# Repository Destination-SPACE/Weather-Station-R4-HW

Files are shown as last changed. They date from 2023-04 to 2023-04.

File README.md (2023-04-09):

# Destination Weather Station R4 - Hardware
Hardware repository for the Destination Weather Station R4 remote sensing platform

## Features
- Seeeduino XIAO SAMD21 M0 microcontroller
- BME280 environmental sensor
- 128x64 OLED display
- microSD card connector
- STEMMA-QT connector
- Sensor Hat mezzanine connectors (reversable)

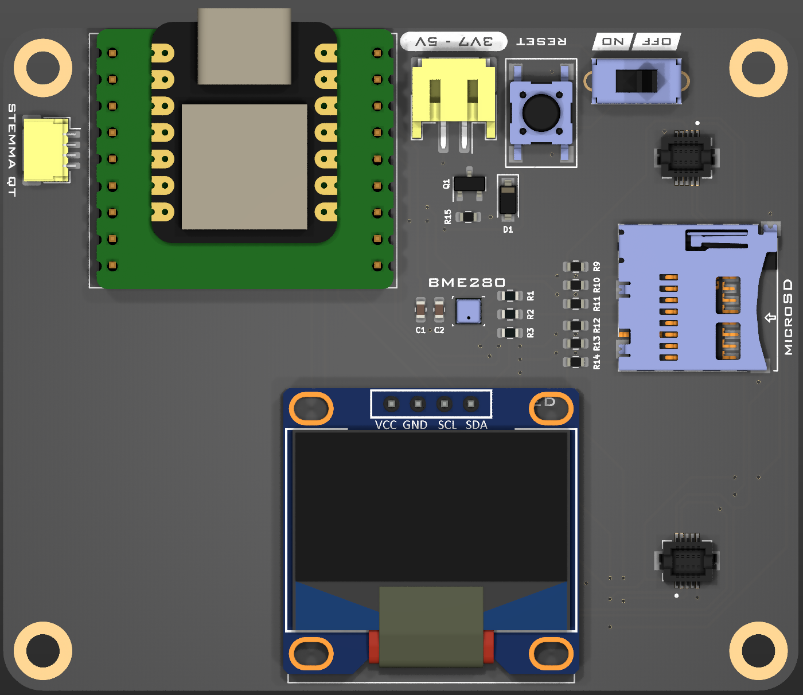
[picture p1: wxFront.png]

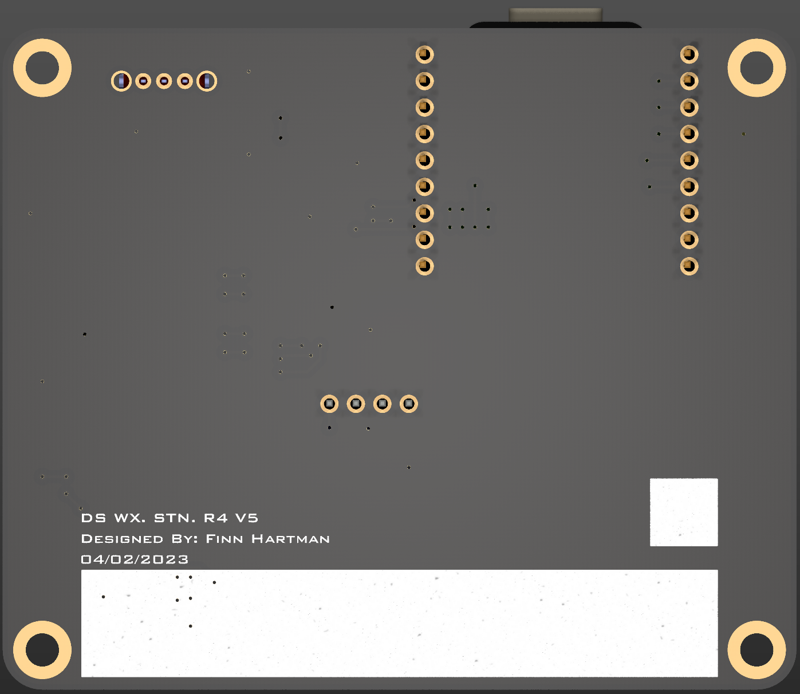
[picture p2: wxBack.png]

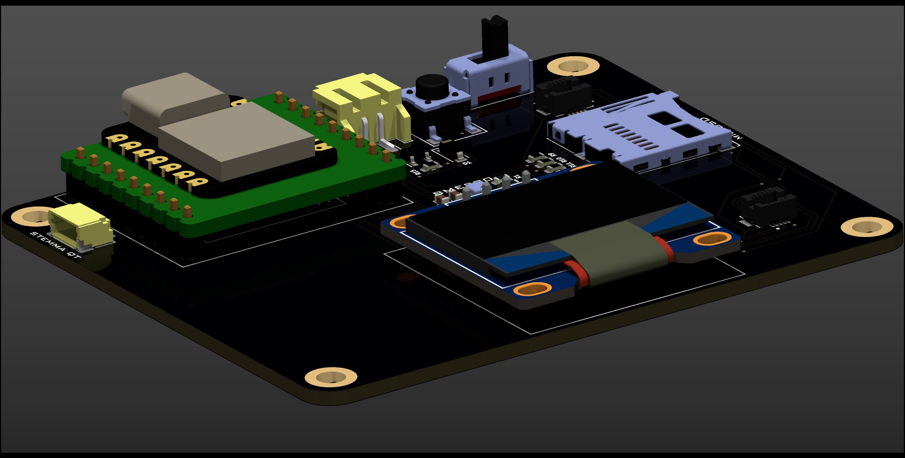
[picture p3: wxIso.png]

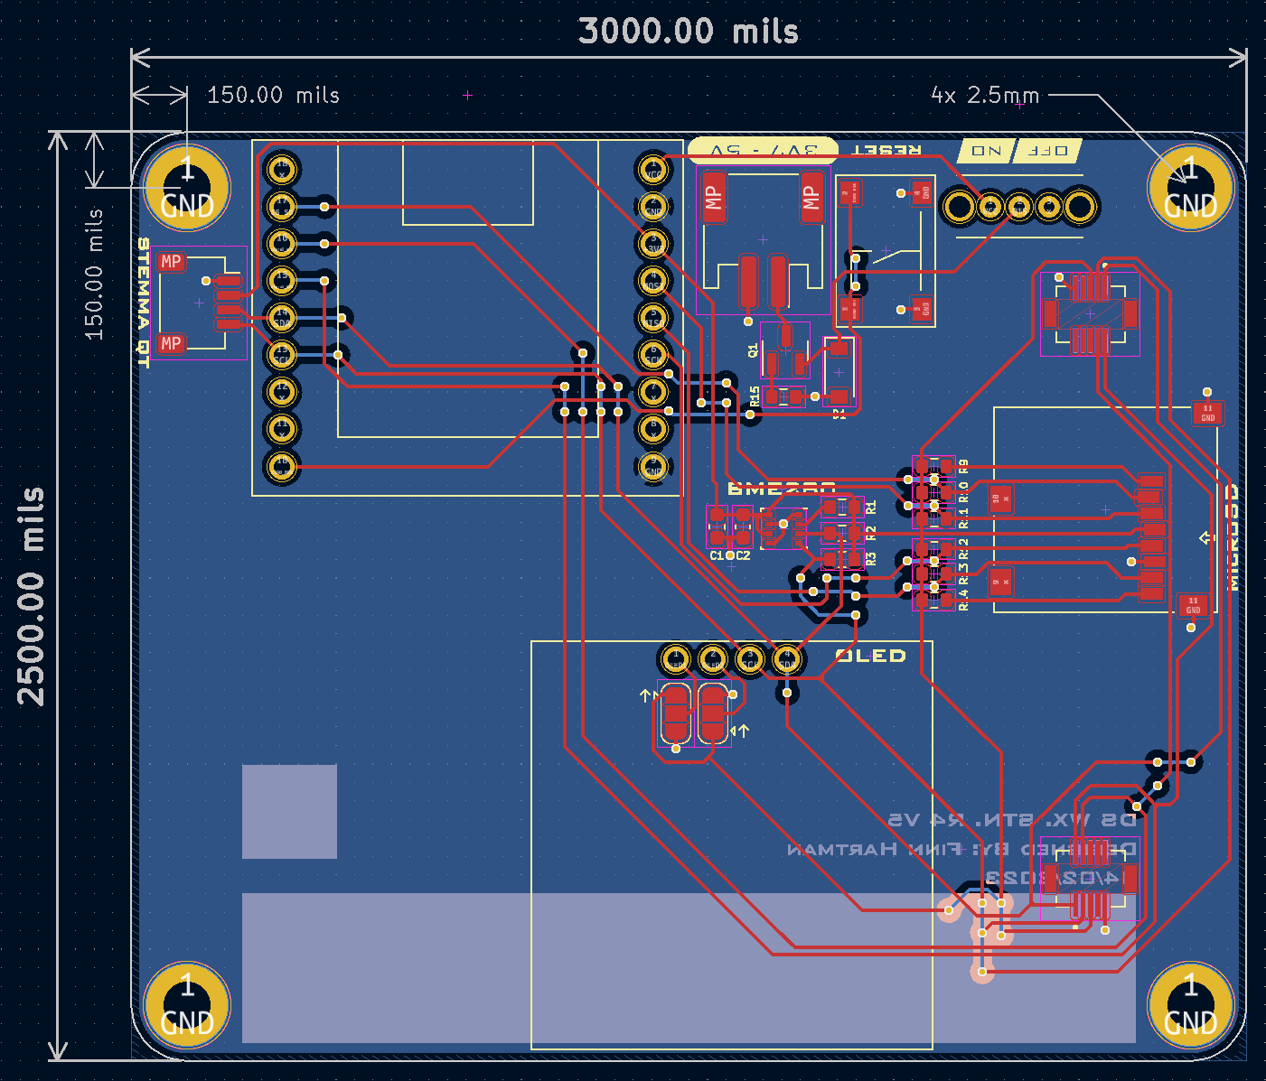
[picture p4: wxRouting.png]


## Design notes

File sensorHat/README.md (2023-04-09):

# Destination Weather Station Sensor Hat - Hardware
Hardware for the Destination Weather Station Sensor Hat environmental sensor expansion board

## Features
- SCD40 CO<sub>2</sub> sensor
- ENS160 VOC & eCO<sub>2</sub> sensor
- GUVA-S12SD UVA (350nm) sensor
- GUVB-S11SD UVB (300nm) sensor
- BH1750 ambient light sensor
- Weather Station mezzanine connectors (reversable)

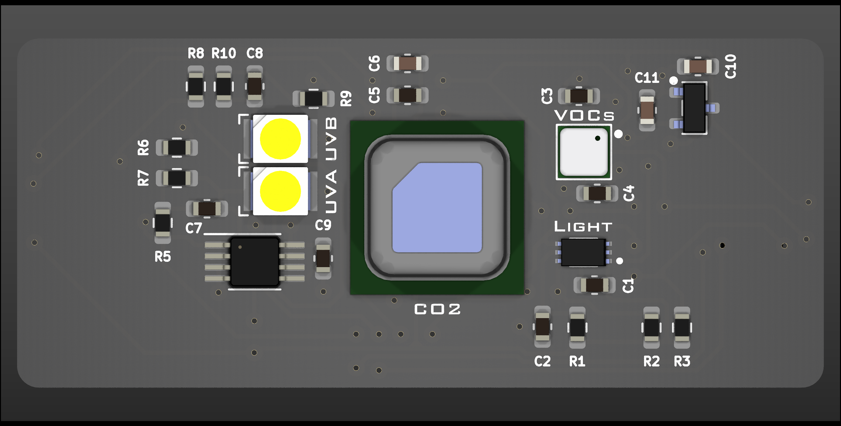
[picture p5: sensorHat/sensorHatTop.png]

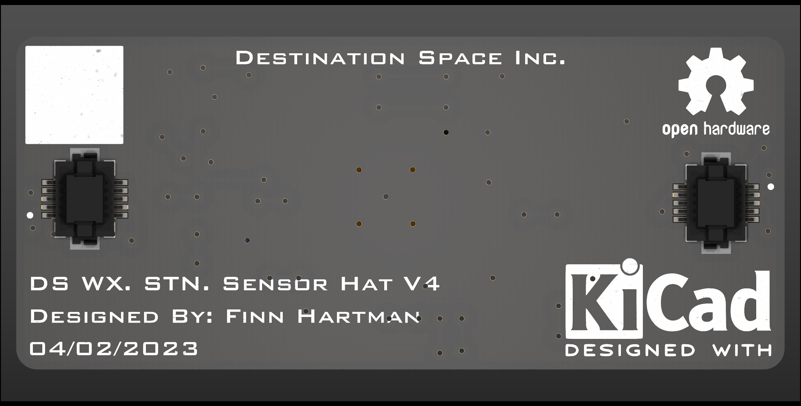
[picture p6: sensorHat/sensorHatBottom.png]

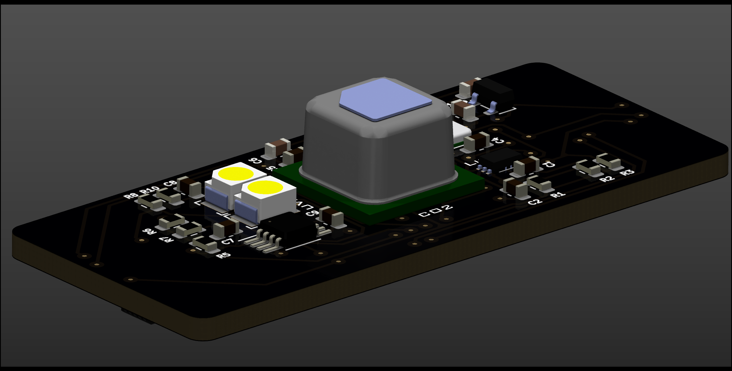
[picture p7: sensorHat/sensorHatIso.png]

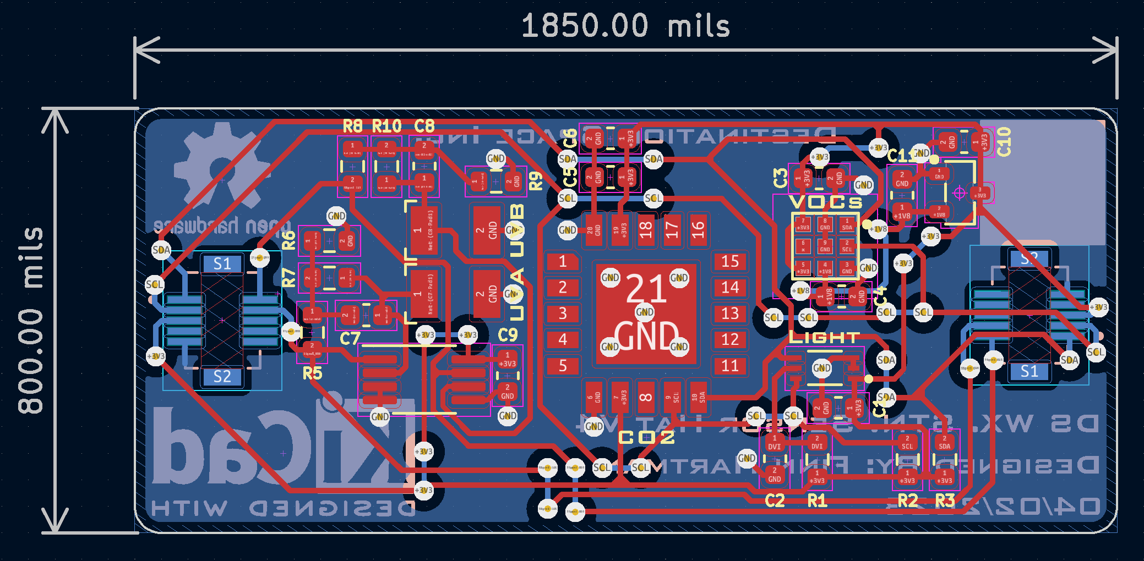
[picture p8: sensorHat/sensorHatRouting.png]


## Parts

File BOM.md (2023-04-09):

| Item | Qty | Reference(s) | Value | Manufacturer | mpn |
| ---- | --- | --- | --- | --- | --- |
| 1 | 2 | C1, C2 | 0.1uF | TDK Corporation | CGA3E2X7R1E104K080AA |
| 2 | 1 | D1 | MMSZ4702T1G | Onsemi | MMSZ4702T1G |
| 4 | 2 | J1, J2 | DF12NB(3.0)-10DP-0.5V(51) | Hirose Electric Co Ltd | DF12NB(3.0)-10DP-0.5V(51) |
| 5 | 1 | J3 | S2B-PH-SM4-TB(LF)(SN) | JST Sales America Inc. | S2B-PH-SM4-TB(LF)(SN) |
| 6 | 1 | J4 | MEM2051-00-195-00-A | GCT | MEM2051-00-195-00-A |
| 7 | 1 | J5 | SM04B-SRSS-TB(LF)(SN) | JST Sales America Inc. | SM04B-SRSS-TB(LF)(SN) |
| 9 | 1 | Q1 | DMP3056L | Diodes Incorporated | DMP3056L-7 |
| 10 | 9 | R1, R2, R3, R9, R10, R11, R12, R13, R14 | 10K | Vishay Dale | CRCW060310K0JNEB |
| 11 | 1 | R15 | 100R | Vishay Dale | CRCW0603100RFKEA |
| 12 | 1 | SW1 | OS102011MS2QS1 | C&K | OS102011MS2QS1 |
| 13 | 1 | SW2 | PTS645SH43SMTR92LFS | C&K | PTS645SH43SMTR92LFS |
| 14 | 1 | U1 | BME280 | Bosch Sensortec | BME280 |
| 15 | 1 | U2 | OLED module | Frienda | B08VNNCLHD |
| 16 | 1 | U3 | Xiao Carrier | Seeed Technology Co., Ltd | 102010328 |

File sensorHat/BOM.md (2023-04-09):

| Item | Qty | Reference(s) | Value | Manufacturer | mpn |
| ---- | --- | --- | --- | --- | --- |
| 1 | 7 | C1, C2, C3, C4, C7, C8, C9 | 0.1uF | TDK Corporation | CGA3E2X7R1E104K080AA |
| 2 | 1 | C5 | 10uF | TDK Corportation | C1608X5R1A106K080AC |
| 3 | 1 | D1 | GUVAS12SD | Genicom Co., Ltd. | GUVA-S12SD |
| 4 | 1 | D2 | GUVBS11SD | Genicom Co., Ltd. | GUVB-S11SD |
| 5 | 2 | J1, J2 | DF12NB(3.0)-10DS-0.5V(51) | Hirose Electric Co Ltd | DF12NB(3.0)-10DS-0.5V(51) |
| 6 | 3 | R1, R6, R9 | 1K | Vishay Dale | CRCW06031K00FKEA |
| 7 | 2 | R2, R3 | 10K | Vishay Dale | CRCW060310K0JNEB |
| 8 | 1 | R4 | 4.7R | Vishay Dale | CRCW06034R70JNEA |
| 9 | 2 | R5, R8 | 3.3K | Vishay Dale | CRCW06033K30FKEA |
| 10 | 2 | R7, R10 | 1M | Vishay Dale | CRCW06031M00FKEA |
| 11 | 1 | U1 | BH1750 | Rohm Semiconductor | BH1750FVI-TR |
| 12 | 1 | U2 | SGP40 | Sensirion AG | SGP40-D-R4 |
| 13 | 1 | U3 | SCD42 | Sensirion AG | SCD40-D-R2 |
| 14 | 1 | U4 | MCP6002-E/MS | Microchip Technology | MCP6002-E/MS |

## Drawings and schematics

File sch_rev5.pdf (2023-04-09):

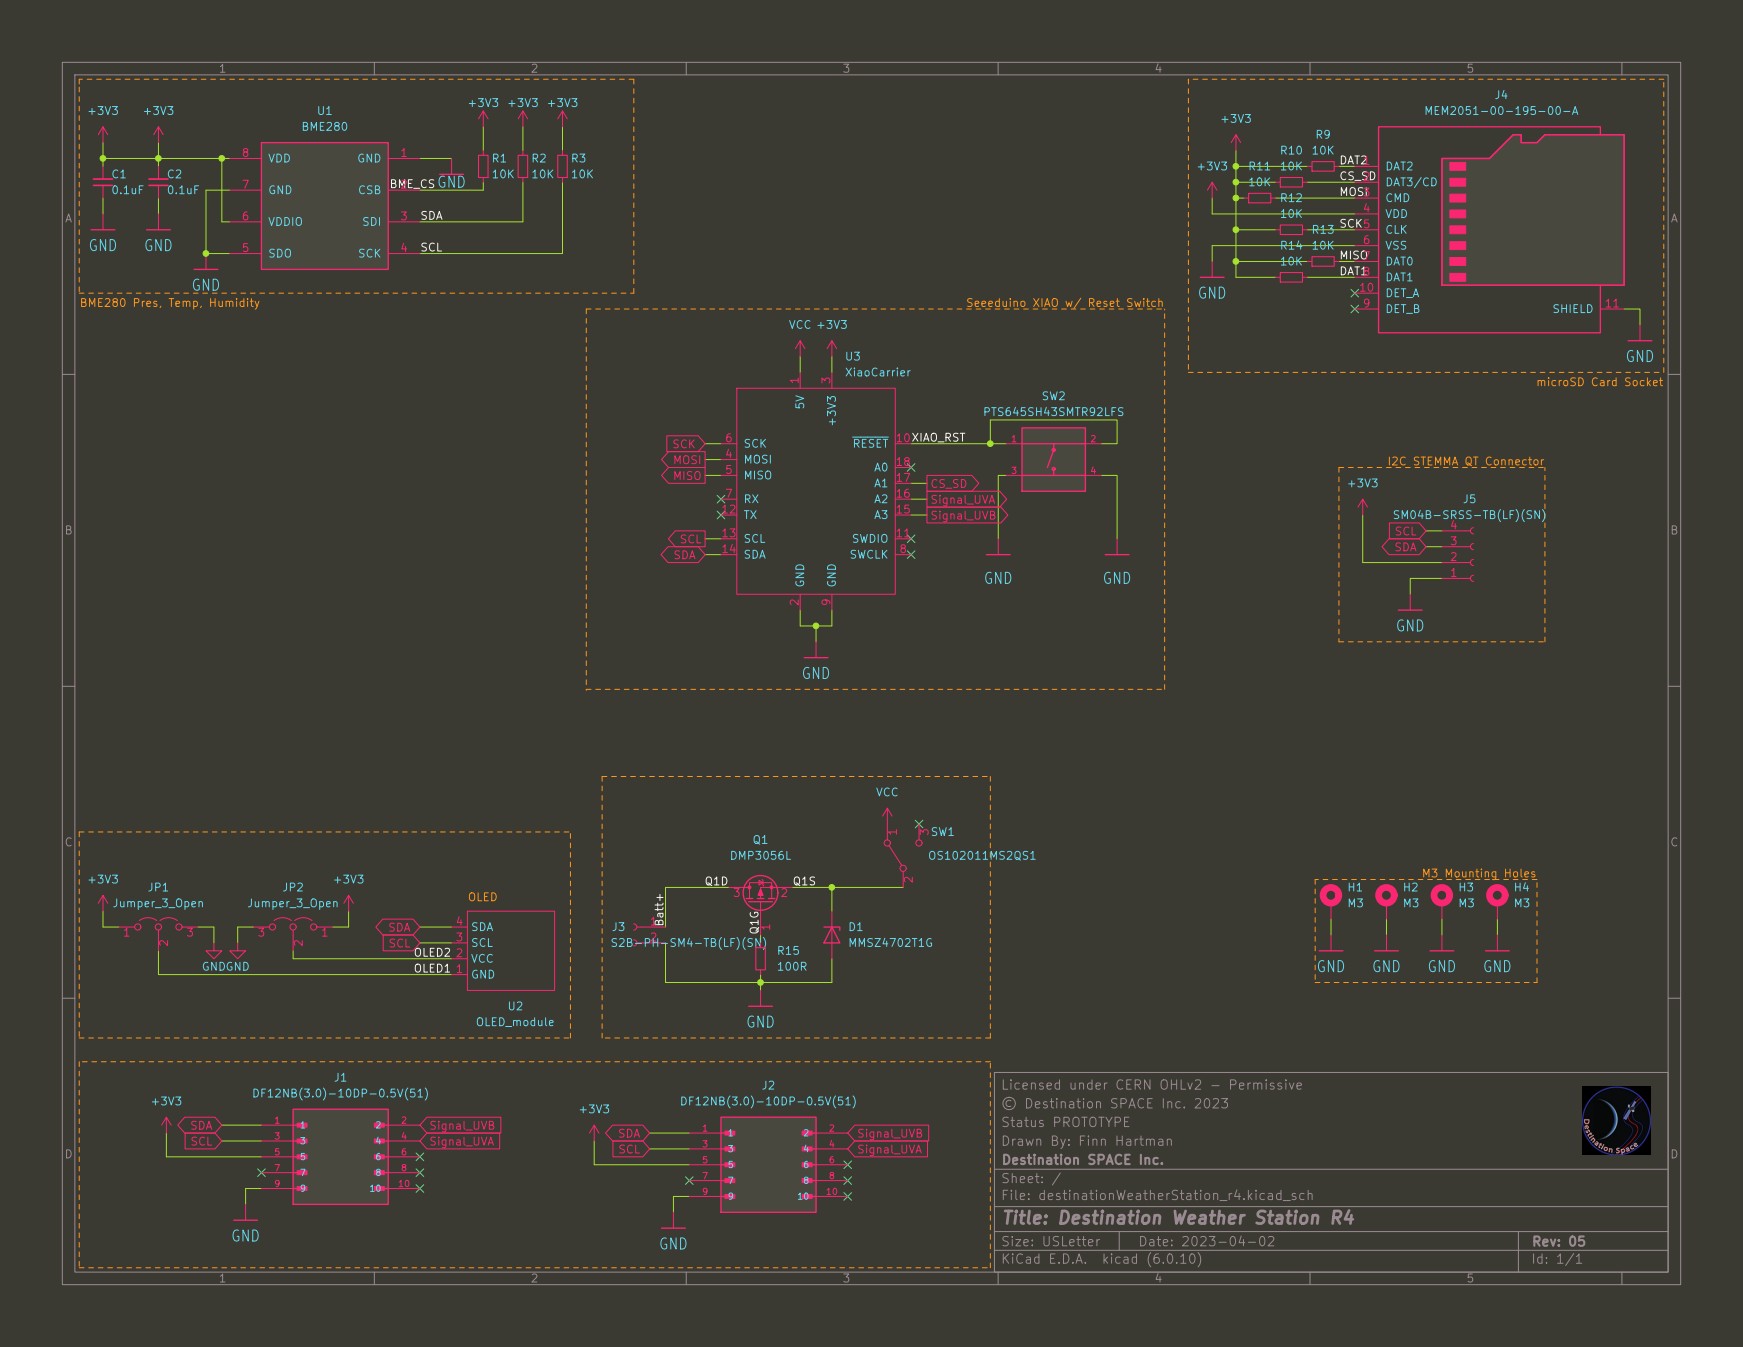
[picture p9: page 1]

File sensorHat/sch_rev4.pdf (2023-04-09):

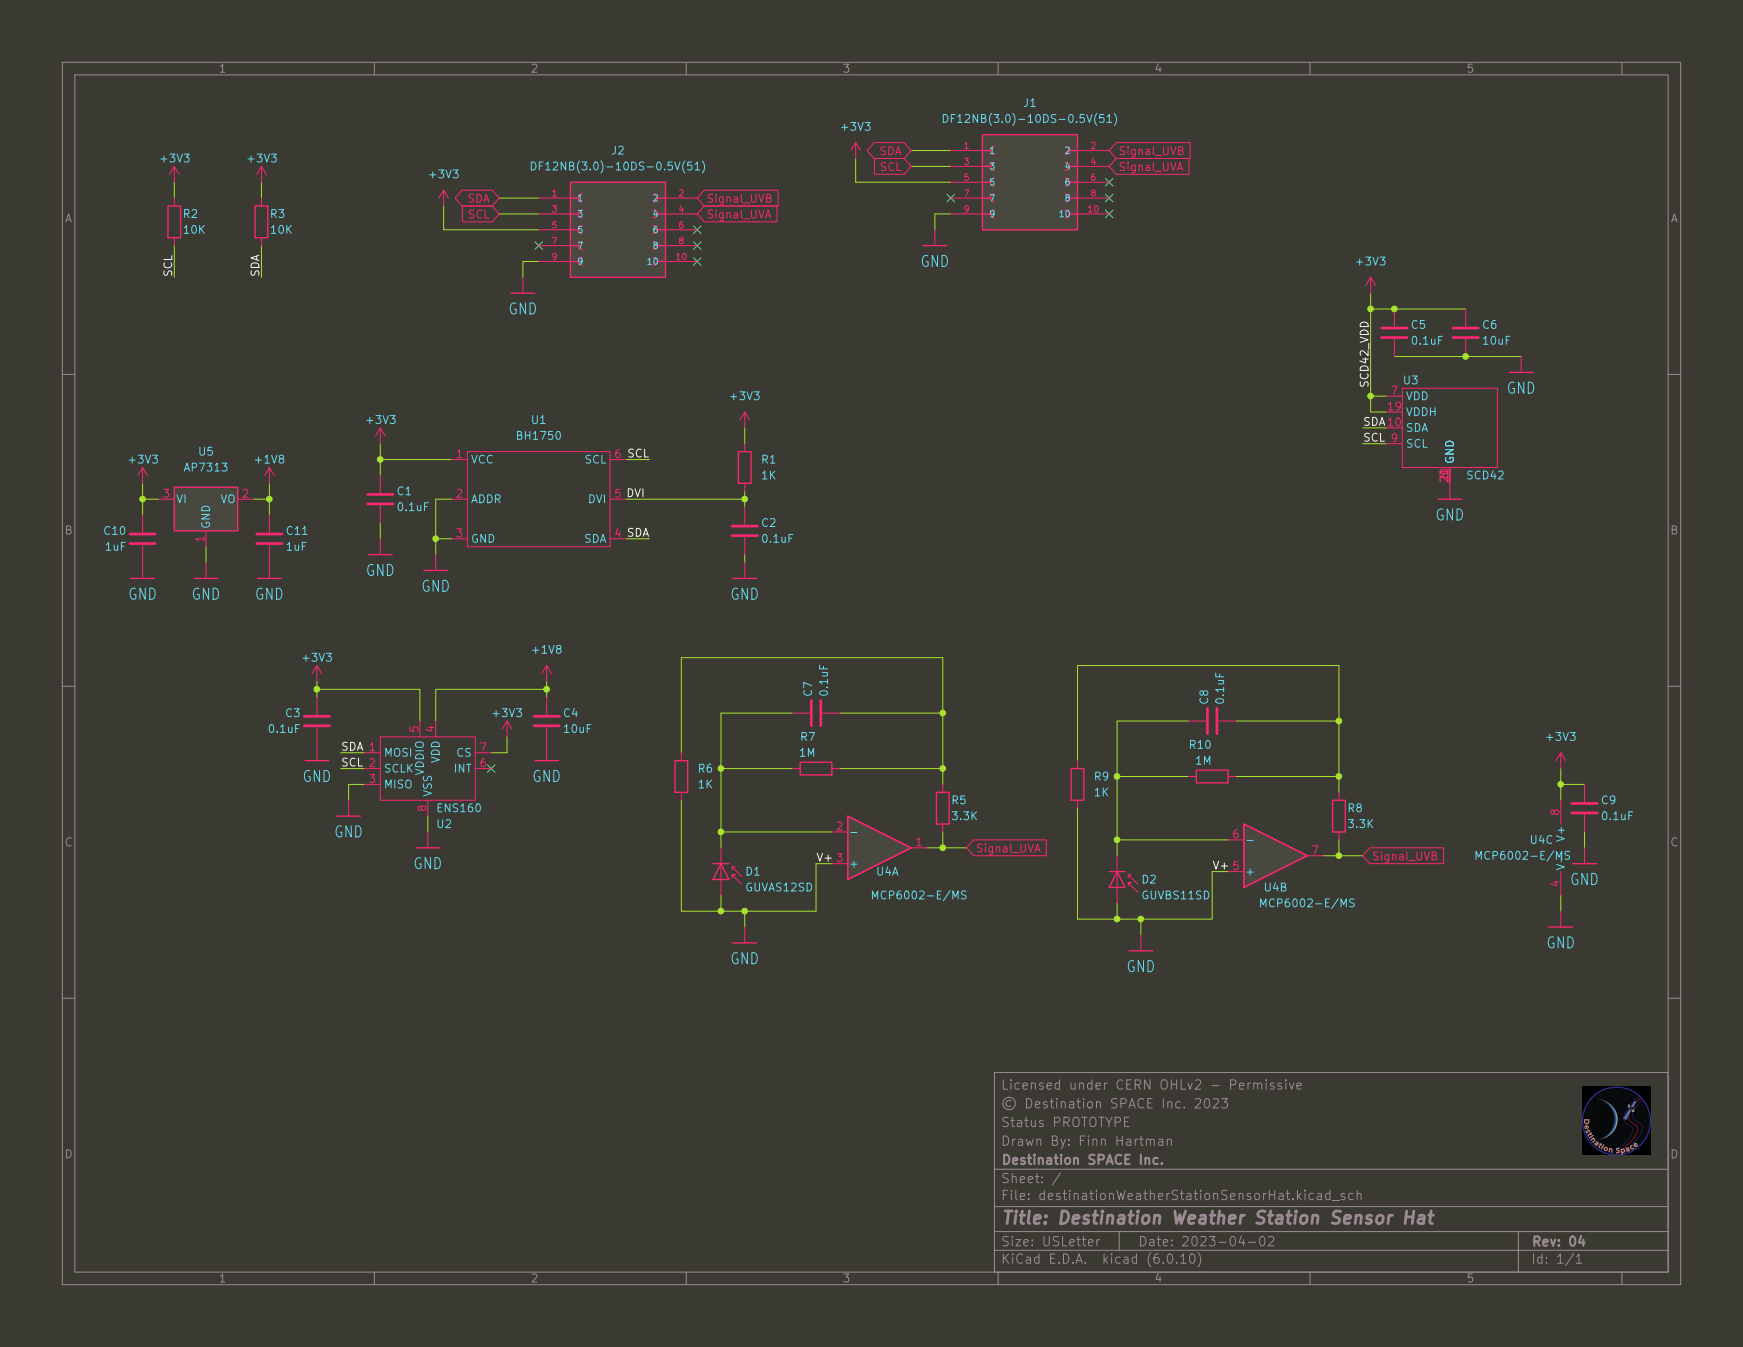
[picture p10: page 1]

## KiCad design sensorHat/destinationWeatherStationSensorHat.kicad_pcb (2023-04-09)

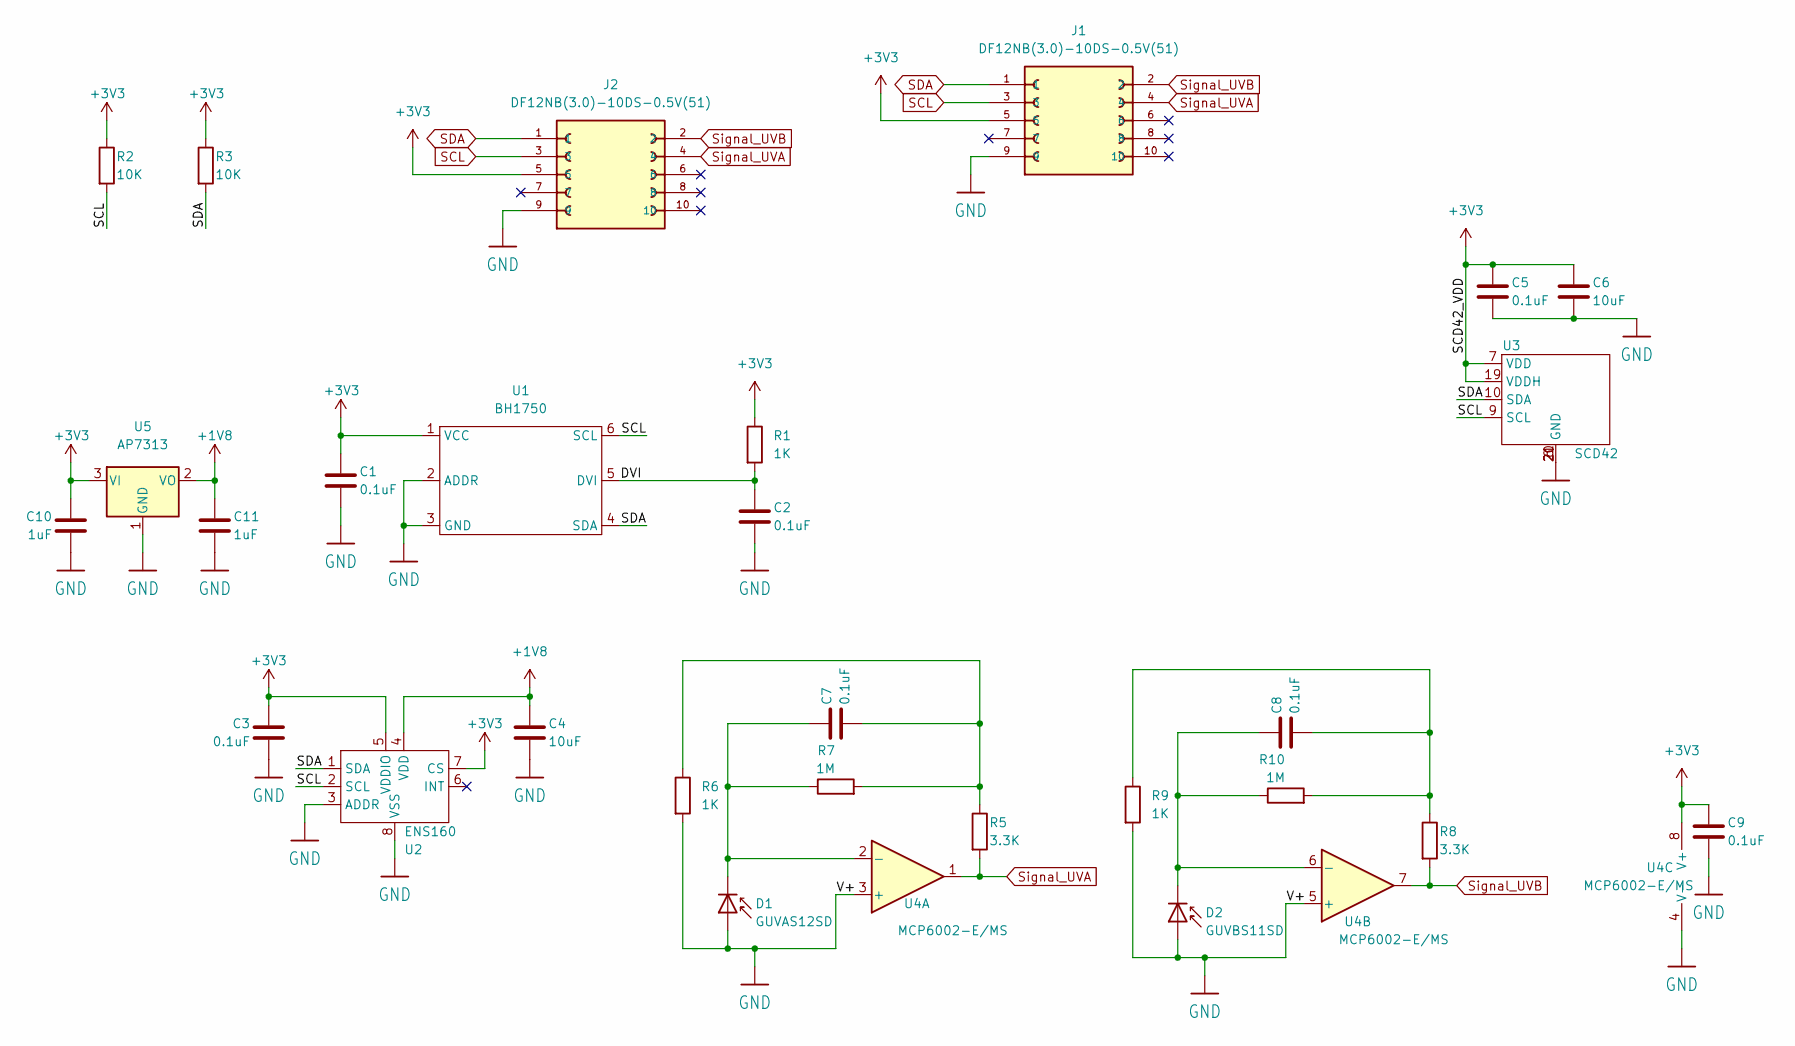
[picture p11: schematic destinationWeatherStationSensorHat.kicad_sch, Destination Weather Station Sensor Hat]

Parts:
C1, C2, C3, C5, C7, C8, C9: 0.1uF; C_0603_1608Metric; mpn CGA3E2X7R1E104K080AA
C4, C6: 10uF; C_0603_1608Metric; mpn C1608X5R1A106K080AC
C10, C11: 1uF; C_0603_1608Metric; mpn CGA3E1X7R1E105K080AC
D1: GUVAS12SD; mpn GUVA-S12SD
D2: GUVBS11SD; GUVAS12SD; mpn GUVB-S11SD
J1, J2: DF12NB(3.0)-10DS-0.5V(51); HRS_DF12NB(3.0)-10DS-0.5V(51); mpn DF12NB(3.0)-10DS-0.5V(51)
R1, R6, R9: 1K; R_0603_1608Metric; mpn CRCW06031K00FKEA
R2, R3: 10K; R_0603_1608Metric; mpn CRCW060310K0JNEB
R5, R8: 3.3K; R_0603_1608Metric; mpn CRCW06033K30FKEA
R7, R10: 1M; R_0603_1608Metric; mpn CRCW06031M00FKEA
U1: BH1750; XDCR_BH1750FVI-TR; mpn BH1750FVI-TR
U2: ENS160; LGA9CP105_3X3_300X300X90L70N; mpn ENS160-BGLM
U3: SCD42; SCD40; mpn SCD40-D-R2
U4: MCP6002-E/MS; MSOP-8_3x3mm_P0.65mm; mpn MCP6002-E/MS
U5: AP7313; AP7313-18SAG-7

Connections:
+1V8: C4.1, C11.1, U2.4 (VDD), U5.2 (VO)
+3V3: C1.1, C3.1, C5.1, C6.1, C9.1, C10.1, J1.5, J2.5, R1.1, R2.1, R3.1, U1.1 (VCC), U2.5 (VDDIO), U2.7 (CS), U3.7 (VDD), U3.19 (VDDH), U4.8 (V+), U5.3 (VI)
/DVI: C2.1, R1.2, U1.5 (DVI)
GND: C1.2, C2.2, C3.2, C4.2, C5.2, C6.2, C9.2, C10.2, C11.2, D1.2 (A), D2.2 (A), J1.9, J2.9, R6.2, R9.2, U1.2 (ADDR), U1.3 (GND), U2.3 (ADDR), U2.8 (VSS), U2.9 (VSS), U3.6 (GND), U3.20 (GND), U3.21 (GND), U4.3 (+), U4.4 (V-), U4.5 (+), U5.1 (GND)
unnamed: C7.1, D1.1 (K), R7.1, U4.2 (-)
unnamed: C7.2, R5.1, R6.1, R7.2
unnamed: C8.1, D2.1 (K), R10.1, U4.6 (-)
unnamed: C8.2, R8.1, R9.1, R10.2
SCL: J1.3, J2.3, R2.2, U1.6 (SCL), U2.2 (SCL), U3.9 (SCL)
SDA: J1.1, J2.1, R3.2, U1.4 (SDA), U2.1 (SDA), U3.10 (SDA)
Signal_UVA: J1.4, J2.4, R5.2, U4.1
Signal_UVB: J1.2, J2.2, R8.2, U4.7

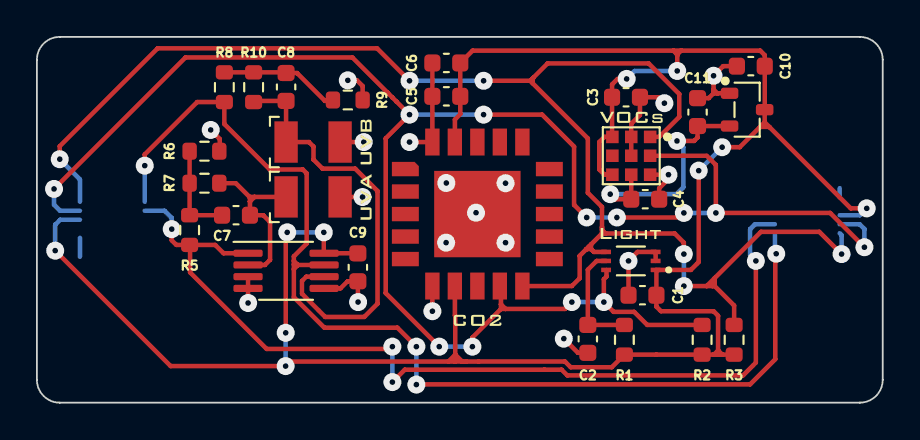
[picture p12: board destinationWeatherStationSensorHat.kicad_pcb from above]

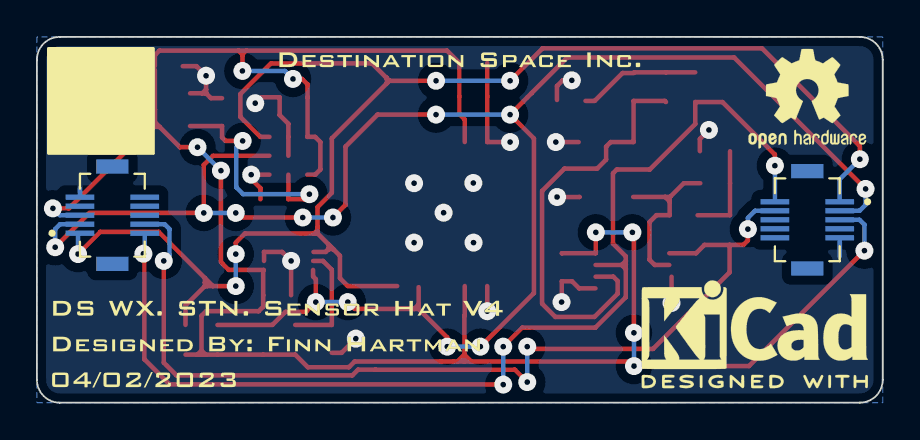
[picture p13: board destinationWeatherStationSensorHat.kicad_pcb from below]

Board: 2 copper layers, 47.0 x 20.3 mm, 36 parts (4 on the bottom side), 12 nets.

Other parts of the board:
kibuzzard-63A142C4: G***; kibuzzard-63A142C4
kibuzzard-63A142D7: G***; kibuzzard-63A142D7
kibuzzard-63A142F5: G***; kibuzzard-63A142F5
kibuzzard-63A14315: G***; kibuzzard-63A14315
kibuzzard-63A14339: G***; kibuzzard-63A14339
kibuzzard-641DA226: G***; kibuzzard-641DA226
kibuzzard-6429C003: G***; kibuzzard-6429C003

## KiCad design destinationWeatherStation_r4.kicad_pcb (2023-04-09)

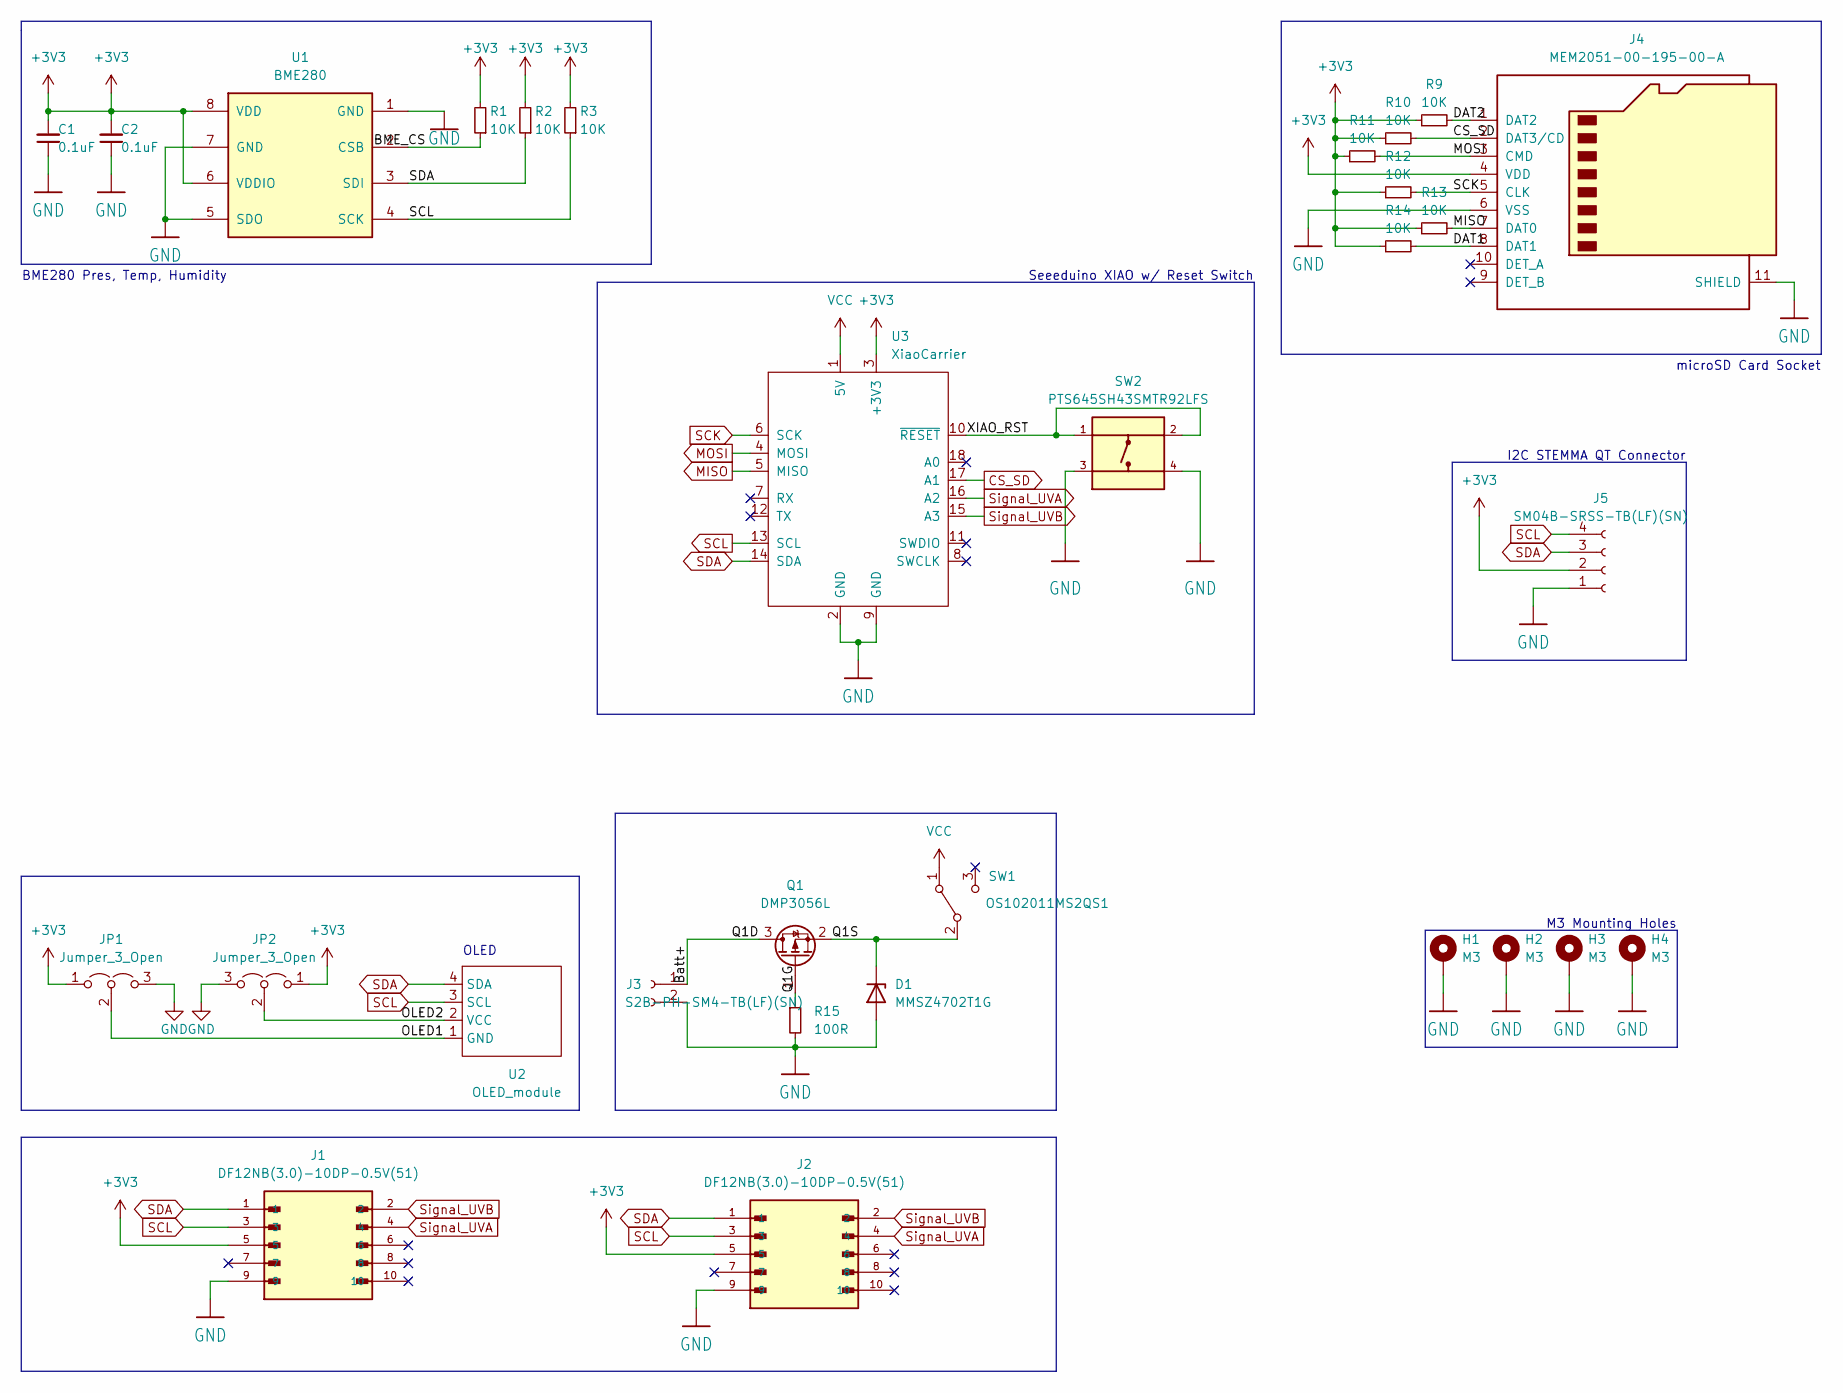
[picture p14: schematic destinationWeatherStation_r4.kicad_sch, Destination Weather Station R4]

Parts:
C1, C2: 0.1uF; C_0603_1608Metric; mpn CGA3E2X7R1E104K080AA
D1: MMSZ4702T1G; D_SOD-123; mpn MMSZ4702T1G
H1, H2, H3, H4: M3; MountingHole_3.2mm_M3_DIN965_Pad
J1, J2: DF12NB(3.0)-10DP-0.5V(51); HRS_DF12NB(3.0)-10DP-0.5V(51); mpn DF12NB(3.0)-10DP-0.5V(51)
J3: S2B-PH-SM4-TB(LF)(SN); JST_PH_S2B-PH-SM4-TB_1x02-1MP_P2.00mm_Horizontal; mpn S2B-PH-SM4-TB(LF)(SN)
J4: MEM2051-00-195-00-A; MF_Connectors-MF-MICROSD; mpn MEM2051-00-195-00-A
J5: SM04B-SRSS-TB(LF)(SN); JST_SH_SM04B-SRSS-TB_1x04-1MP_P1.00mm_Horizontal; mpn SM04B-SRSS-TB(LF)(SN)
JP1, JP2: Jumper_3_Open; SolderJumper-3_P1.3mm_Open_RoundedPad1.0x1.5mm
Q1: DMP3056L; SOT-23; mpn DMP3056L-7
R1, R2, R3, R9, R10, R11, R12, R13, R14: 10K; R_0603_1608Metric; mpn CRCW060310K0JNEB
R15: 100R; R_0603_1608Metric; mpn CRCW0603100RFKEA
SW1: OS102011MS2QS1; SW_SPDT; mpn OS102011MS2QS1
SW2: PTS645SH43SMTR92LFS; MF_Switches-TACT6MM; mpn PTS645SH43SMTR92LFS
U1: BME280; Bosch_LGA-8_2.5x2.5mm_P0.65mm_ClockwisePinNumbering; mpn BME280
U2: OLED_module
U3: XiaoCarrier; mpn 102010328

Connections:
+3V3: C1.2, C2.2, J1.5, J2.5, J4.4 (VDD), J5.2, JP1.1 (A), JP2.1 (A), R1.2, R2.2, R3.2, R9.1, R10.1, R11.1, R12.1, R13.1, R14.1, U1.6 (VDDIO), U1.8 (VDD), U3.3 (+3V3)
/BME_CS: R1.1, U1.2 (CSB)
/Batt+: J3.1, Q1.3 (D)
/DAT1: J4.8 (DAT1), R14.2
/DAT2: J4.1 (DAT2), R9.2
/OLED1: JP1.2 (C), U2.1 (GND)
/OLED2: JP2.2 (C), U2.2 (VCC)
/Q1G: Q1.1 (G), R15.1
/Q1S: D1.1 (K), Q1.2 (S), SW1.2 (B)
/XIAO_RST: SW2.1, SW2.2, U3.10 (~RESET)
CS_SD: J4.2 (DAT3/CD), R10.2, U3.17 (A1)
GND: C1.1, C2.1, D1.2 (A), H1.1, H2.1, H3.1, H4.1, J1.9, J2.9, J3.2, J4.6 (VSS), J4.11 (SHIELD), J5.1, JP1.3 (B), JP2.3 (B), R15.2, SW2.3, SW2.4, U1.1 (GND), U1.5 (SDO), U1.7 (GND), U3.2 (GND), U3.9 (GND)
MISO: J4.7 (DAT0), R13.2, U3.5 (MISO)
MOSI: J4.3 (CMD), R11.2, U3.4 (MOSI)
SCK: J4.5 (CLK), R12.2, U3.6 (SCK)
SCL: J1.3, J2.3, J5.4, R3.1, U1.4 (SCK), U2.3 (SCL), U3.13 (SCL)
SDA: J1.1, J2.1, J5.3, R2.1, U1.3 (SDI), U2.4 (SDA), U3.14 (SDA)
Signal_UVA: J1.4, J2.4, U3.16 (A2)
Signal_UVB: J1.2, J2.2, U3.15 (A3)
VCC: SW1.1 (A), U3.1 (5V)

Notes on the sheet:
I2C STEMMA QT Connector
BME280 Pres, Temp, Humidity
OLED
Seeeduino XIAO w/ Reset Switch
M3 Mounting Holes
microSD Card Socket

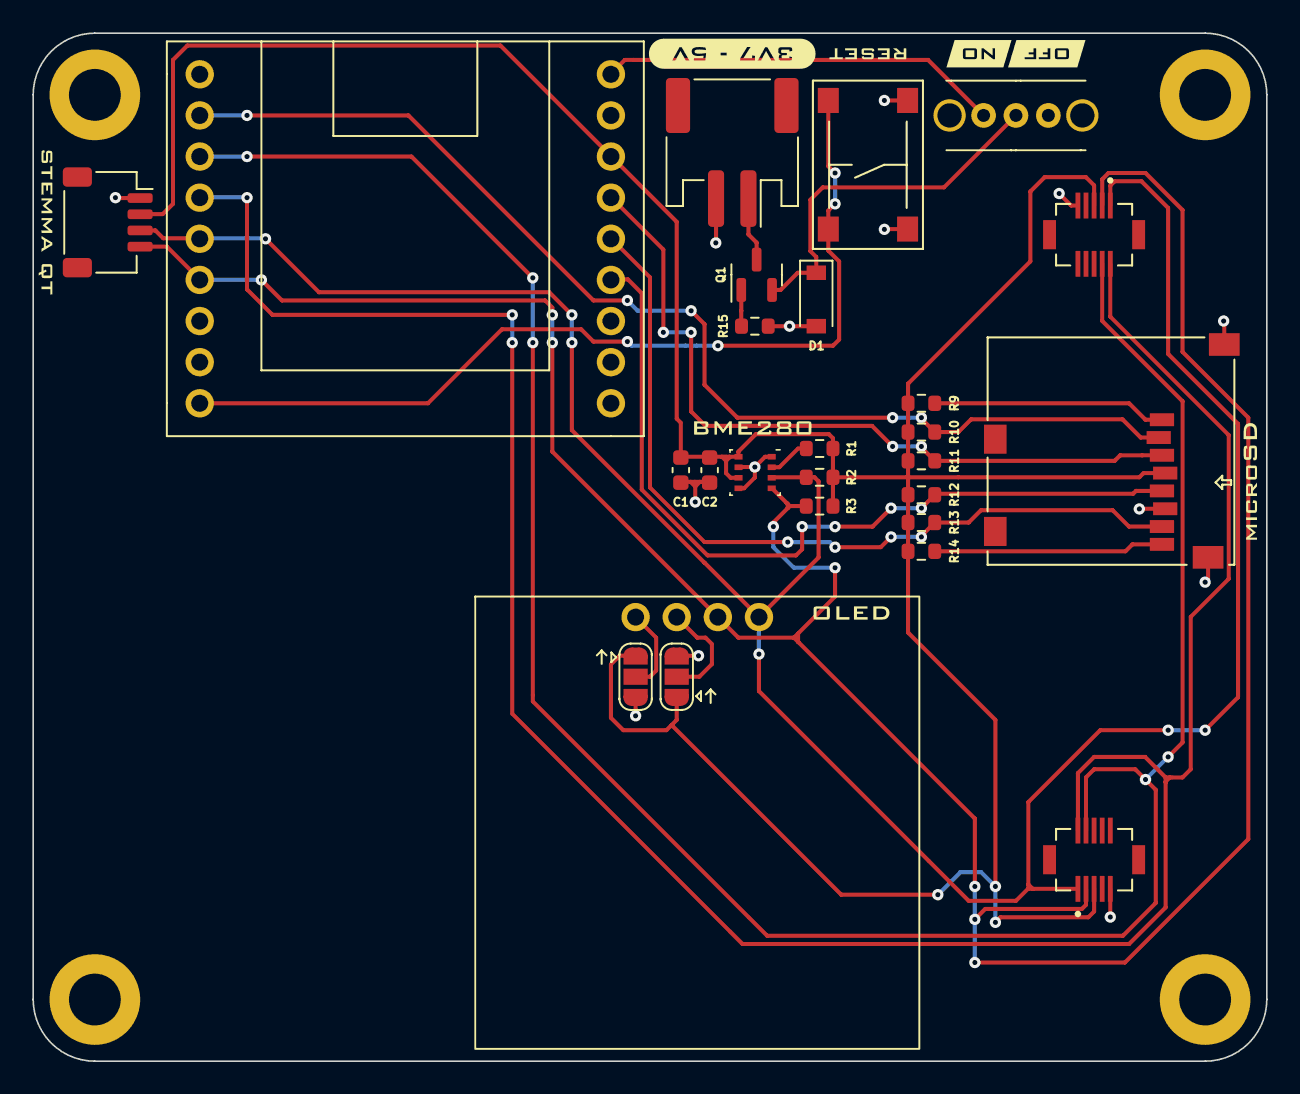
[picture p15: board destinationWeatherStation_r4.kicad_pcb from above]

Board: 2 copper layers, 76.2 x 63.5 mm, 39 parts (1 on the bottom side), 20 nets.

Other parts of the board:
kibuzzard-63A143BA: G***; kibuzzard-63A143BA
kibuzzard-63A146BA: G***; kibuzzard-63A146BA
kibuzzard-63A147A6: G***; kibuzzard-63A147A6
kibuzzard-63A1452B: G***; kibuzzard-63A1452B
kibuzzard-63A14452: G***; kibuzzard-63A14452
kibuzzard-63A14586: G***; kibuzzard-63A14586
kibuzzard-6429C5F6: G***; kibuzzard-6429C5F6
kibuzzard-64039D9C: G***; kibuzzard-64039D9C
kibuzzard-64039D84: G***; kibuzzard-64039D84
